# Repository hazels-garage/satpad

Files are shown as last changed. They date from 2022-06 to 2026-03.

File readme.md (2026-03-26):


<a href="https://discord.gg/jP6hvgNN8r">
  
</a>

# SatPad

30% ortholinear keyboard built using ergogen v3. 

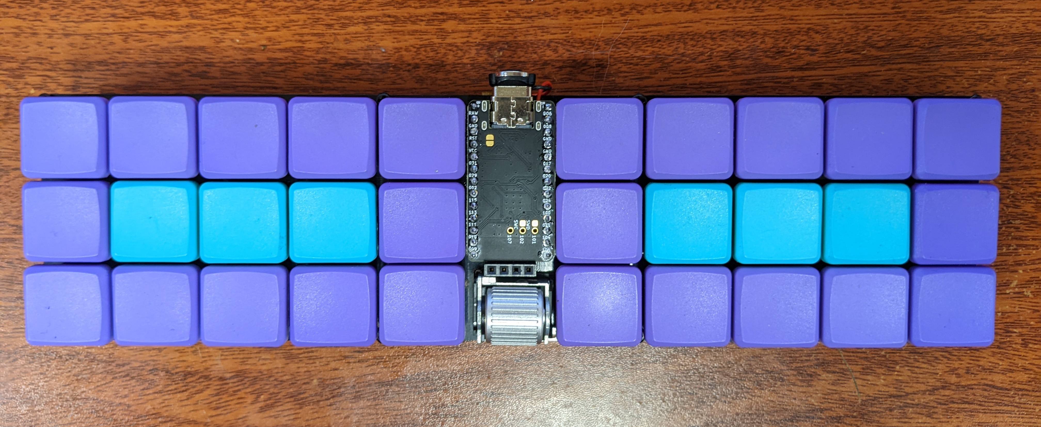
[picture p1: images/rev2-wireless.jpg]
rev2
 
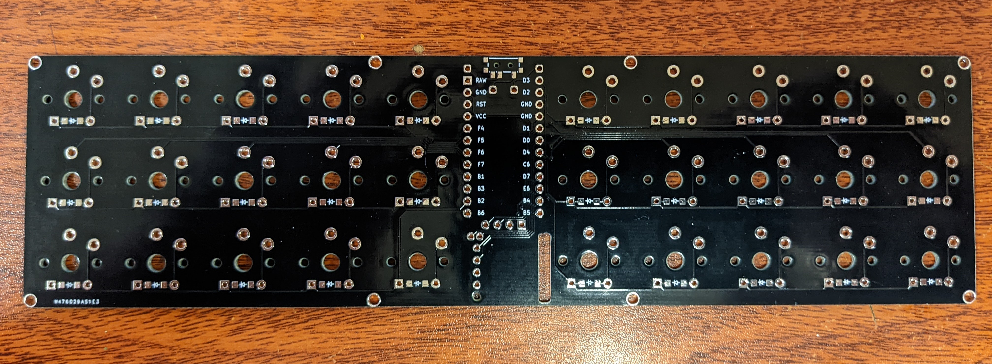
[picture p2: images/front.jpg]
front
 
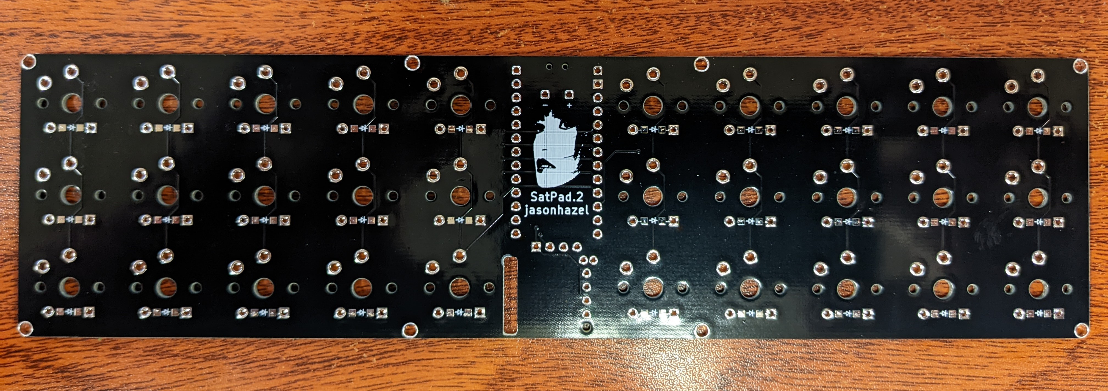
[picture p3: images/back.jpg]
back


## ERGOGEN V3!
I have not updated this project to use Ergogen v4 and am unlikely to do so.

## Features

- 30 key ortholinear split (10 column, 3 row)
- scroll wheel encoder with click
- OLED display

## Sponsored by PCBWay
This project was initially just to learn, but PCBWay reached out and offered to sponsor further development.  They've been awesome - great quality, fast fabrication and great customer service.  I'll definitely be using them for future projects.

<a href="https://www.pcbway.com/project/shareproject/SatPad_rev2_53e17b07.html">Order on PCBWay</a>
## Ergogen
built using my customized fork of ergogen that adds a bunch of footprints.

https://github.com/jasonhazel/ergogen/tree/jasonhazel

## Materials
* 1x ProMicro or equivalent
* 1x SSD1306 OLED Screen (optional, QMK Only)
* 30x 1N4148 SOD-123 Diodes
* 30x Kailh Choc v1
* 30x 1u Kailh Choc Keycaps
* 1x EVQWGD001 Encoder
* 1x C128955 Switch (optional)
* 1x LiPo Battery (optional)

## Firmware
QMK: https://github.com/jasonhazel/qmk_firmware/tree/hazel/satpad

ZMK: https://github.com/jasonhazel/zmk-config/tree/satpad

## Keymap
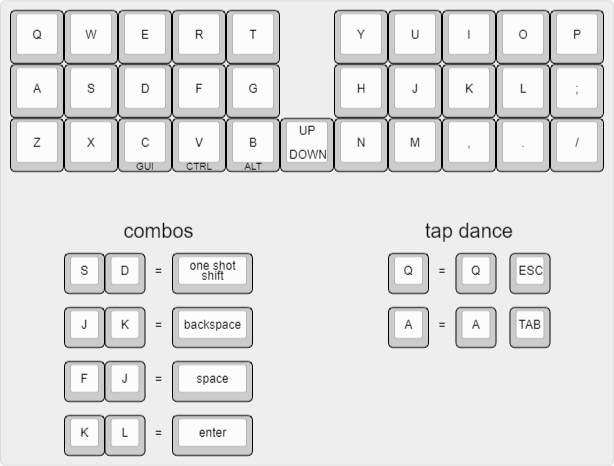
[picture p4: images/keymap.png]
Keymap


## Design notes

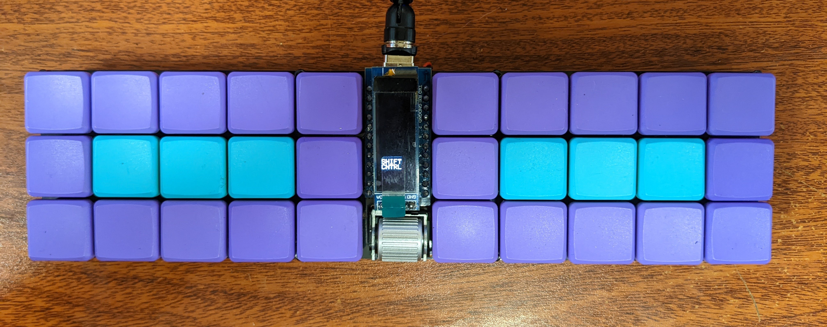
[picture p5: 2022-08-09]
images/rev2-wired.jpg

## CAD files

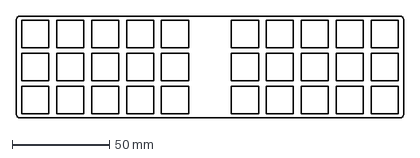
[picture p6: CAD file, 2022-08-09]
output/outlines/switch_plate.dxf
199.5 x 52.5 mm

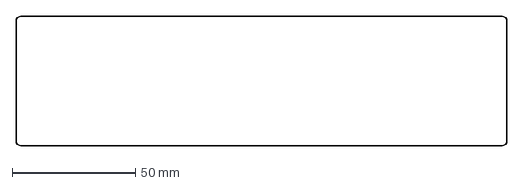
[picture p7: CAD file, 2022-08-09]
output/outlines/panel.dxf
199.5 x 52.5 mm

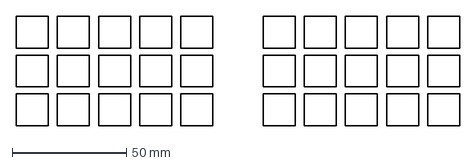
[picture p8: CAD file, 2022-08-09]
output/outlines/switch_cutouts.dxf
194.0 x 48.0 mm

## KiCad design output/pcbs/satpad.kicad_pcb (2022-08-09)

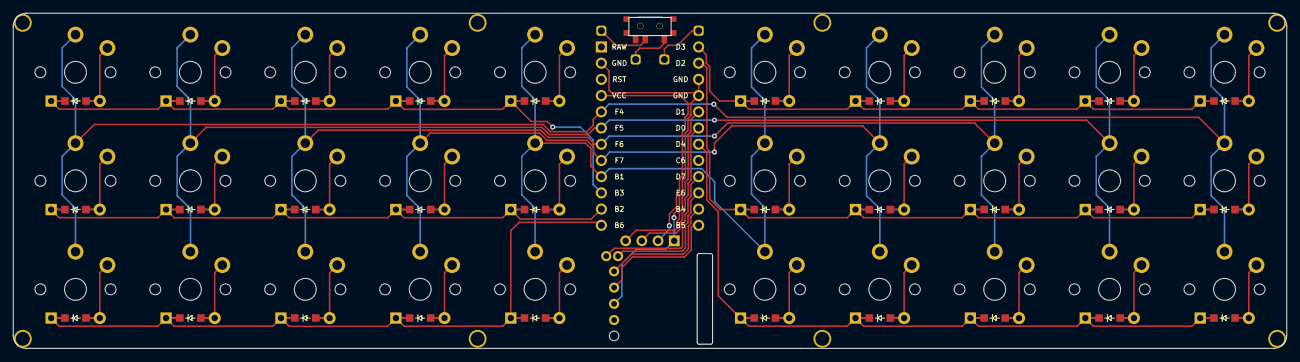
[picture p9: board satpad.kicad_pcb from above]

Board: 2 copper layers, 199.5 x 52.5 mm, 63 parts (0 on the bottom side), 46 nets.

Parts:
D1, D2, D3, D4, D5, D6, D7, D8, D9, D10, D11, D12, D13, D14, D15, D16, D17, D18, D19, D20, D21, D22, D23, D24, D25, D26, D27, D28, D29, D30: ComboDiode
MCU1: ProMicro
OLED1: OLED; OLED_headers
S1, S2, S3, S4, S5, S6, S7, S8, S9, S10, S11, S12, S13, S14, S15, S16, S17, S18, S19, S20, S21, S22, S23, S24, S25, S26, S27, S28, S29, S30: PG1350
T1: SPDT_C128955

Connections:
B1: MCU1.9, S13.2, S14.2, S15.2, S28.2, S29.2, S30.2
B2: D2.1, D2.2, D5.1, D5.2, D8.1, D8.2, D11.1, D11.2, D14.1, D14.2, MCU1.11
B3: D3.1, D3.2, D6.1, D6.2, D9.1, D9.2, D12.1, D12.2, D15.1, D15.2, MCU1.10
B6: D1.1, D1.2, D4.1, D4.2, D7.1, D7.2, D10.1, D10.2, D13.1, D13.2, MCU1.12
Bplus: MCU1.25, T1.2
D0: MCU1.18, OLED1.3
D1: MCU1.17, OLED1.4
D2: D17.1, D17.2, D20.1, D20.2, D23.1, D23.2, D26.1, D26.2, D29.1, D29.2, MCU1.14
D3: D18.1, D18.2, D21.1, D21.2, D24.1, D24.2, D27.1, D27.2, D30.1, D30.2, MCU1.13
D4: D16.1, D16.2, D19.1, D19.2, D22.1, D22.2, D25.1, D25.2, D28.1, D28.2, MCU1.19
F4: MCU1.5, S1.2, S2.2, S3.2, S16.2, S17.2, S18.2
F5: MCU1.6, S4.2, S5.2, S6.2, S19.2, S20.2, S21.2
F6: MCU1.7, S7.2, S8.2, S9.2, S22.2, S23.2, S24.2
F7: MCU1.8, S10.2, S11.2, S12.2, S25.2, S26.2, S27.2
GND: MCU1.2, MCU1.15, MCU1.16, OLED1.1
VCC: MCU1.4, OLED1.2
index_bottom: D10.1, D10.2, S10.1
index_home: D11.1, D11.2, S11.1
index_top: D12.1, D12.2, S12.1
inner_bottom: D13.1, D13.2, S13.1
inner_home: D14.1, D14.2, S14.1
inner_top: D15.1, D15.2, S15.1
middle_bottom: D7.1, D7.2, S7.1
middle_home: D8.1, D8.2, S8.1
middle_top: D9.1, D9.2, S9.1
mirror_index_bottom: D25.1, D25.2, S25.1
mirror_index_home: D26.1, D26.2, S26.1
mirror_index_top: D27.1, D27.2, S27.1
mirror_inner_bottom: D28.1, D28.2, S28.1
mirror_inner_home: D29.1, D29.2, S29.1
mirror_inner_top: D30.1, D30.2, S30.1
mirror_middle_bottom: D22.1, D22.2, S22.1
mirror_middle_home: D23.1, D23.2, S23.1
mirror_middle_top: D24.1, D24.2, S24.1
mirror_pinky_bottom: D16.1, D16.2, S16.1
mirror_pinky_home: D17.1, D17.2, S17.1
mirror_pinky_top: D18.1, D18.2, S18.1
mirror_ring_bottom: D19.1, D19.2, S19.1
mirror_ring_home: D20.1, D20.2, S20.1
mirror_ring_top: D21.1, D21.2, S21.1
pinky_bottom: D1.1, D1.2, S1.1
pinky_home: D2.1, D2.2, S2.1
pinky_top: D3.1, D3.2, S3.1
ring_bottom: D4.1, D4.2, S4.1
ring_home: D5.1, D5.2, S5.1
ring_top: D6.1, D6.2, S6.1

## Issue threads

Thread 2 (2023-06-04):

Battery Routing

Zylanx, 2023-06-04:
The battery should be routed to GND and RAW, not to headers in the position of B+ and B- on the nice!nano which are intended for direct connection of the battery.

This is the very first point on the official docs here: https://nicekeyboards.com/docs/nice-nano/getting-started/

"Do not install sockets or post headers to the B+ or B- pins (top pin on each side)
If you need to use these pins with your PCB, RAW and GND are the respective equivalents to B+ and B-"

Zylanx, 2023-06-04:
I'd probably make a pull request but I broke my arm, unfortunately

jasonhazel, 2023-06-04:
Yeah, you're 100% right on that. SatPad was my very first design and I definitely made some mistakes while making it.  I've moved on from this project though so won't be making any updates. I will accept pull requests.

Zylanx, 2023-06-04:
All good! You're able to use kicad properly which is better than me! Once I'm back in action I'll remember to have a go

Closed 2025-06-24.

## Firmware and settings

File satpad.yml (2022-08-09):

units:
  h: cy
  w: cx
  mount_offset: .5h - .75
mounting:
  mount1:
    type: m2
    params.size: 2.8
    anchor:
      ref: 
        - matrix_pinky_top
        # - matrix_ring_top
      shift: [-.5w + .75, mount_offset]
  mount2:
    type: m2
    params.size: 2.8
    anchor:
      ref: 
        - matrix_pinky_bottom
      shift: [-.5w + .75, -mount_offset]
      
  mount3:
    type: m2
    params.size: 2.8
    anchor:
      ref: 
        - matrix_index_top
        - matrix_inner_top
      shift: [0, mount_offset]
  mount4:
    type: m2
    params.size: 2.8
    anchor:
      ref:
        - matrix_index_bottom
        - matrix_inner_bottom
      shift: [0, -mount_offset] 
  mount5:
    type: m2
    params.size: 2.8
    anchor:
      ref: 
        - mirror_matrix_pinky_top
      shift: [.5w - .75, mount_offset]
  mount6:
    type: m2
    params.size: 2.8
    anchor:
      ref: 
        - mirror_matrix_pinky_bottom
      shift: [.5w - .75, -mount_offset]
  mount7:
    type: m2
    params.size: 2.8
    anchor:
      ref: 
        - mirror_matrix_index_top
        - mirror_matrix_inner_top
      shift: [0, mount_offset]
  mount8:
    type: m2
    params.size: 2.8
    anchor:
      ref:
        - mirror_matrix_index_bottom
        - mirror_matrix_inner_bottom
      shift: [0, -mount_offset]       

swaps:
  diode:
    footprints.diode.anchor.shift: [0, 8]
points:
  mirror:
    ref: matrix_inner_home
    distance: 2w
  zones:
    matrix:
      columns:
        pinky:
          key:
            column_net: F4
        ring:
          spread: w
          key:
            column_net: F5
        middle:
          spread: w
          key:
            column_net: F6
        index:
          spread: w
          key.column_net: F7
        inner:
          spread:  w
          key:
            column_net: B1
      rows:
        bottom:
          padding: h
          row_net: B6
          mirror.row_net: D4
        home:
          padding: h
          row_net: B2
          mirror.row_net: D2

        top:
          padding: h
          row_net: B3
          mirror.row_net: D3
  key:
    bind: 2
    mirror:
      footprints:

    footprints:
      choc:
        type: choc
        anchor:
        nets:
          from: =colrow
          to: =column_net
        params:
          keycaps: true
      diode:
        type: diode
        anchor:
          shift: [ 0, -4.5 ]
        nets:
          from: =colrow
          to: =row_net
        params:
          padSize: 1.2
          tht: true
          side: both
          via: false
outlines:
  exports:
    raw:
      - type: rectangle
        size: [11w + 1.5,3h + 1.5]
        anchor:
          shift: [-.5w - .75, -.5h - .75]
        corner: 2
    panel:
      - type: outline
        name: raw
        fillet: 0.5
    switch_cutouts:
      - type: keys
        side: both
        size: 14
        bound: false
    switch_plate:
      main:
        type: outline
        name: panel
        fillet: 0.5
      keyholes:
        type: outline
        name: switch_cutouts
        operation: subtract
    backplate:
      - type: outline
        name: panel
pcbs:
  backplate:
    include_keys: false
    outlines:
      main:
        outline: backplate
    footprints:
      $extends: mounting
  plate:
    include_keys: false
    outlines:
      main:
        outline: switch_plate
    footprints:
      $extends: mounting
  satpad:
    outlines:
      main:
        outline: panel
    footprints:
      $extends: 
        - mounting
      promicro:
        type: promicro
        anchor:
          ref: 
            - matrix_inner_top
            - mirror_matrix_inner_top
          shift: [0,-10]
          rotate: -90
        params:
          orientation: down
      oled:
        type: oled
        anchor:
          ref: 
            - matrix_inner_bottom
            - mirror_matrix_inner_bottom
          shift: [-6, 6]
          rotate: 90
        nets:
          SDA: D1
          SCL: D0
      scrollwheel:
        type: scrollwheel
        anchor: 
          ref: 
            - matrix_inner_bottom
            - mirror_matrix_inner_bottom
          shift: [0, -1]
        nets:
          from: D7
          to: E6
          A: B4
          B: B5
          C: GND
          D: ''
      slider:
        type: slider
        anchor:
          ref: 
            - matrix_inner_top
            - mirror_matrix_inner_top
          shift: [0, 7.25]
          # rotate: 180
        nets:
          to: Bplus
          from: BAT
        params:
          side: F
      bat_plus:
        type: pin
        anchor:
          ref: 
            - matrix_inner_top
            - mirror_matrix_inner_top
          shift: [-2.25, 2]
        nets:
          net: BAT
        params:
          shape: roundrect
      bat_plus_silk:
        type: text
        anchor: 
          ref: 
            - matrix_inner_top
            - mirror_matrix_inner_top
          shift: [-2.25,0]
        params:
          text: '+'
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

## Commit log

2022-06-29 added disclaimer about prototype
2022-07-05 cleanup and gerbers
    [panel.dxf, raw.dxf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]
2022-08-09 restructuring files
    [backplate-B_Cu.gbr, backplate-B_Mask.gbr, backplate-B_Paste.gbr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]
2022-08-10 add pcbway order link
2022-08-10 added board images

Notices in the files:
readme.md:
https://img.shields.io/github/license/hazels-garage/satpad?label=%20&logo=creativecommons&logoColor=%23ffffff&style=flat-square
